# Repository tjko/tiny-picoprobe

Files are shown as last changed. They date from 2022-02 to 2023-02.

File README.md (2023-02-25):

# tiny-picoprobe

Tiny PicoProbe is a small PCB to mount Raspberry Pi Pico, when you want to use [PicoProbe](https://github.com/raspberrypi/picoprobe) to debug your [Raspberry Pi Pico](https://www.raspberrypi.com/products/raspberry-pi-pico/) projects without a breadboard...

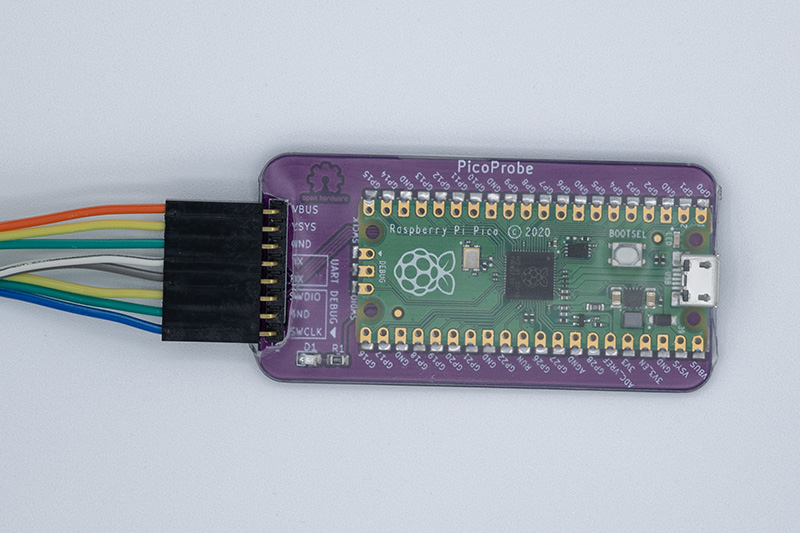
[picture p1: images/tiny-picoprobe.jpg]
Shrinkwrapped Tiny PicoProbe


This was created to make it "handsfree" to update firmware when developing [Fanpico (Smart PWM (PC) Fan Controller)](https://github.com/tjko/fanpico).

If you are not already familiar with PicoProbe see Appendix A in [Getting Started With Pico (PDF)](https://datasheets.raspberrypi.com/pico/getting-started-with-pico.pdf).

There is also tutorial here: [Raspberry Pi Pico and RP2040 - C/C++ Part 2: Debugging with VS Code](https://www.digikey.com/en/maker/projects/raspberry-pi-pico-and-rp2040-cc-part-2-debugging-with-vs-code/470abc7efb07432b82c95f6f67f184c0)

**Update (February 2023)**: There is finally official "picoprobe" available: [Raspberry Pi Debug Probe](https://www.raspberrypi.com/products/debug-probe/).  
which may be better choice if you're looking for ready-made solution. But if you prefer a DIY solution, continue reading...

New Debug Probe makes "tiny-picoprobe" look not so small anymore:

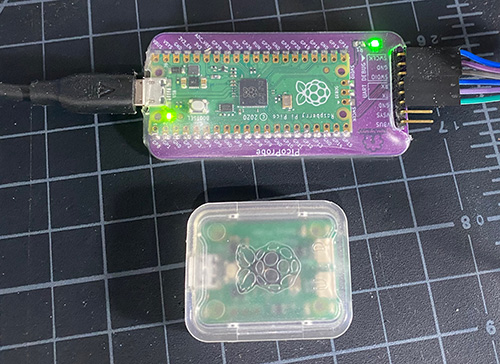
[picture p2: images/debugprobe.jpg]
size comparison


## PCB
PCB provides pinout to connect to Pico's SWD ("DEBUG") connector with flat (3-pin) ribbon cable, and it also has pinouts for UART and powering the Pico being programmed/debugged.

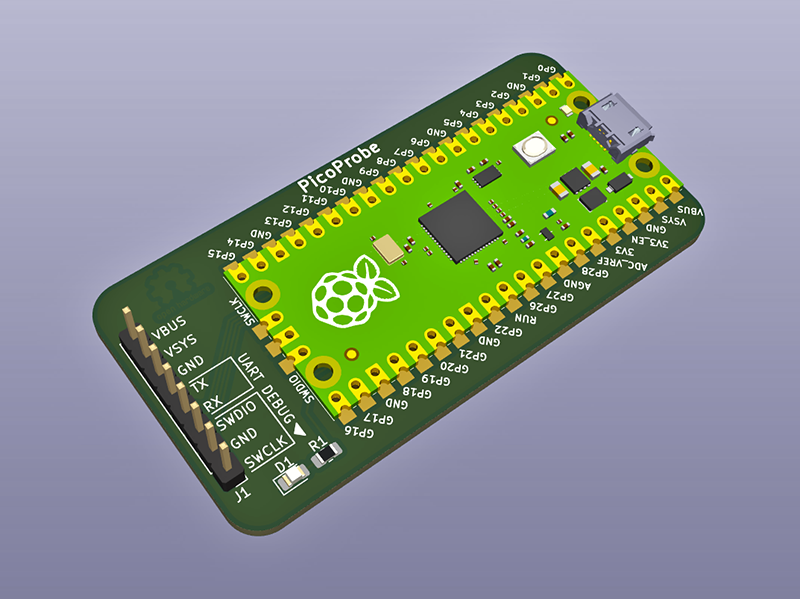
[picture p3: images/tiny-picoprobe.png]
Tiny PicoProbe PCB


Designed with [KiCad](https://www.kicad.org/) 6.0.  PCB allows mounting Pico directly or using headers:

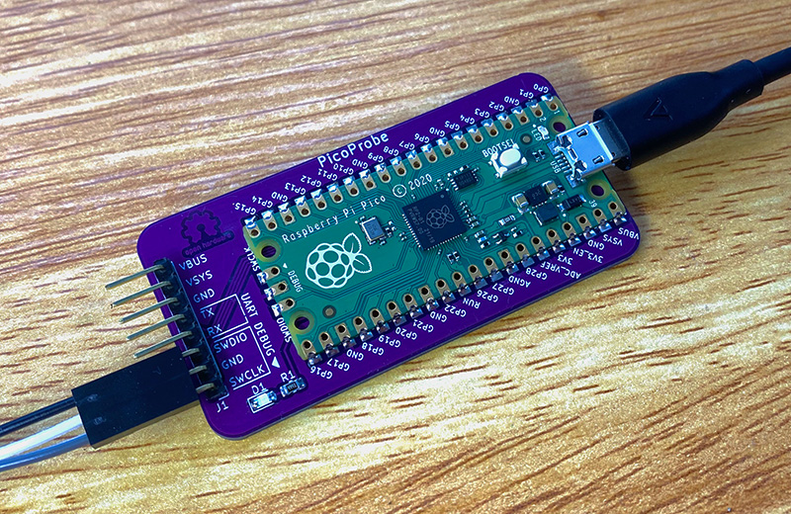
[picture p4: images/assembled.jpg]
Assembled Tiny PicoProbe

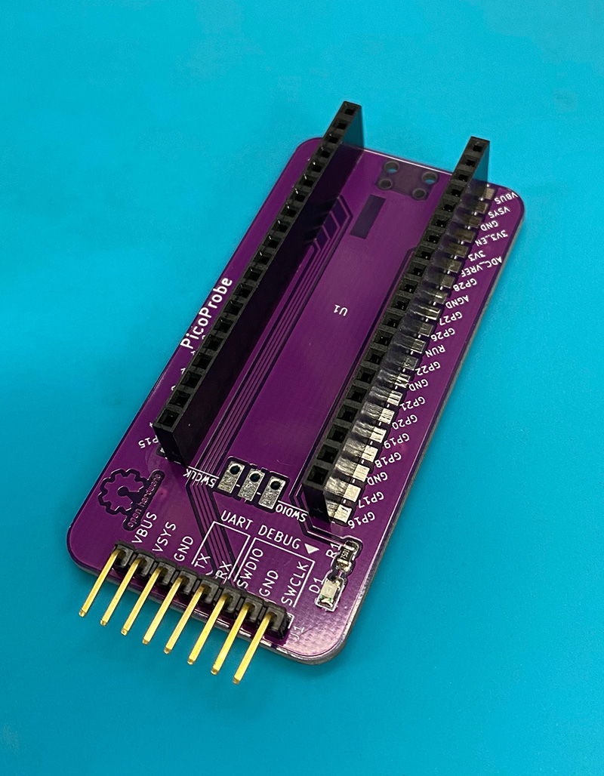
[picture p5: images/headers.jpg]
Tiny PicoProbe with headers


## Kerbers
Kerber files ready to be sent to a PCB maker (like JLCPCB, PCBWay, etc...):
* [PCB Version 1.0](kerbers/tiny-picoprobe-v1.zip)
* [PCB Version 1.1](kerbers/tiny-picoprobe-v1.1.zip)

You will only need the ZIP file (link above) to order PCBs. Simply upload the ZIP file to a PCB maker website. Then you typically only need to only select quantity and PCB color. If ordering from JLCPCB you can also choose to "Specify a location" in the Remove Order Number option (this will place order number on the PCB so that the Pico will cover it).

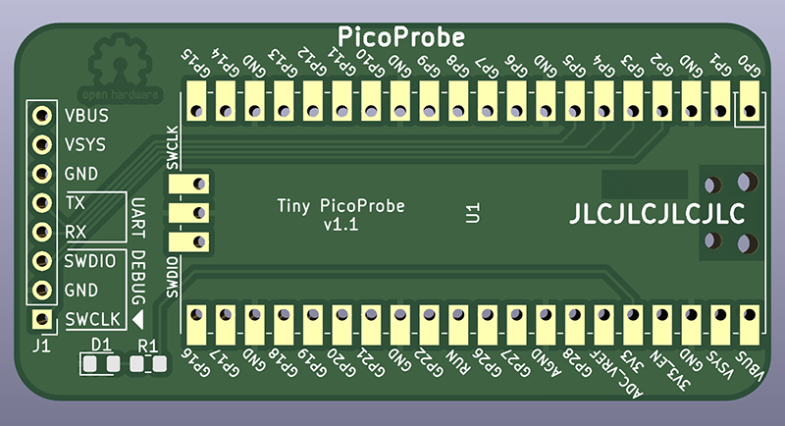
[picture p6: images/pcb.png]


## Assembly
PCB contains footprints for a 0805 size SMD LED and resistor to provide power indicator. Power indicator is optional.

ID|Type|Description|Mouser P/N|LCSC P/N
--|----|-----------|----------|---------
D1|LED (0805)|Pad is suitable for handsoldering 0805 size LEDs, 0603 should work as well...|710-150080GS75000 (?)|C434432
R1|7.5k (0805)|Depending on LED used choose appropriate resistor. Green high-intensity 0805 LEDs typically work nicely with resistor in 5k to 10k range|603-RC0805FR-077K5L|C229003

Note, if soldering Pico directly on the PCB, then 1" diameter shrink tubing can be used to wrap the pico and PCB in nice insulated package.

## DIY Kits

If you'd like to support Open Source Hardware development.  DIY Kits are made available in limited quantity.

Check availability here: [eBay](https://www.ebay.com/usr/oh6lxv)

## Credits
Idea for this PCB came from [Fabien-Chouteau/picoprobe-pcb](https://github.com/Fabien-Chouteau/picoprobe-pcb) (check his version as he sells it on Tindie).

KiCad Pico model/footprint that was used can be found here [ncarandini/KiCad-RP-Pico](https://github.com/ncarandini/KiCad-RP-Pico)

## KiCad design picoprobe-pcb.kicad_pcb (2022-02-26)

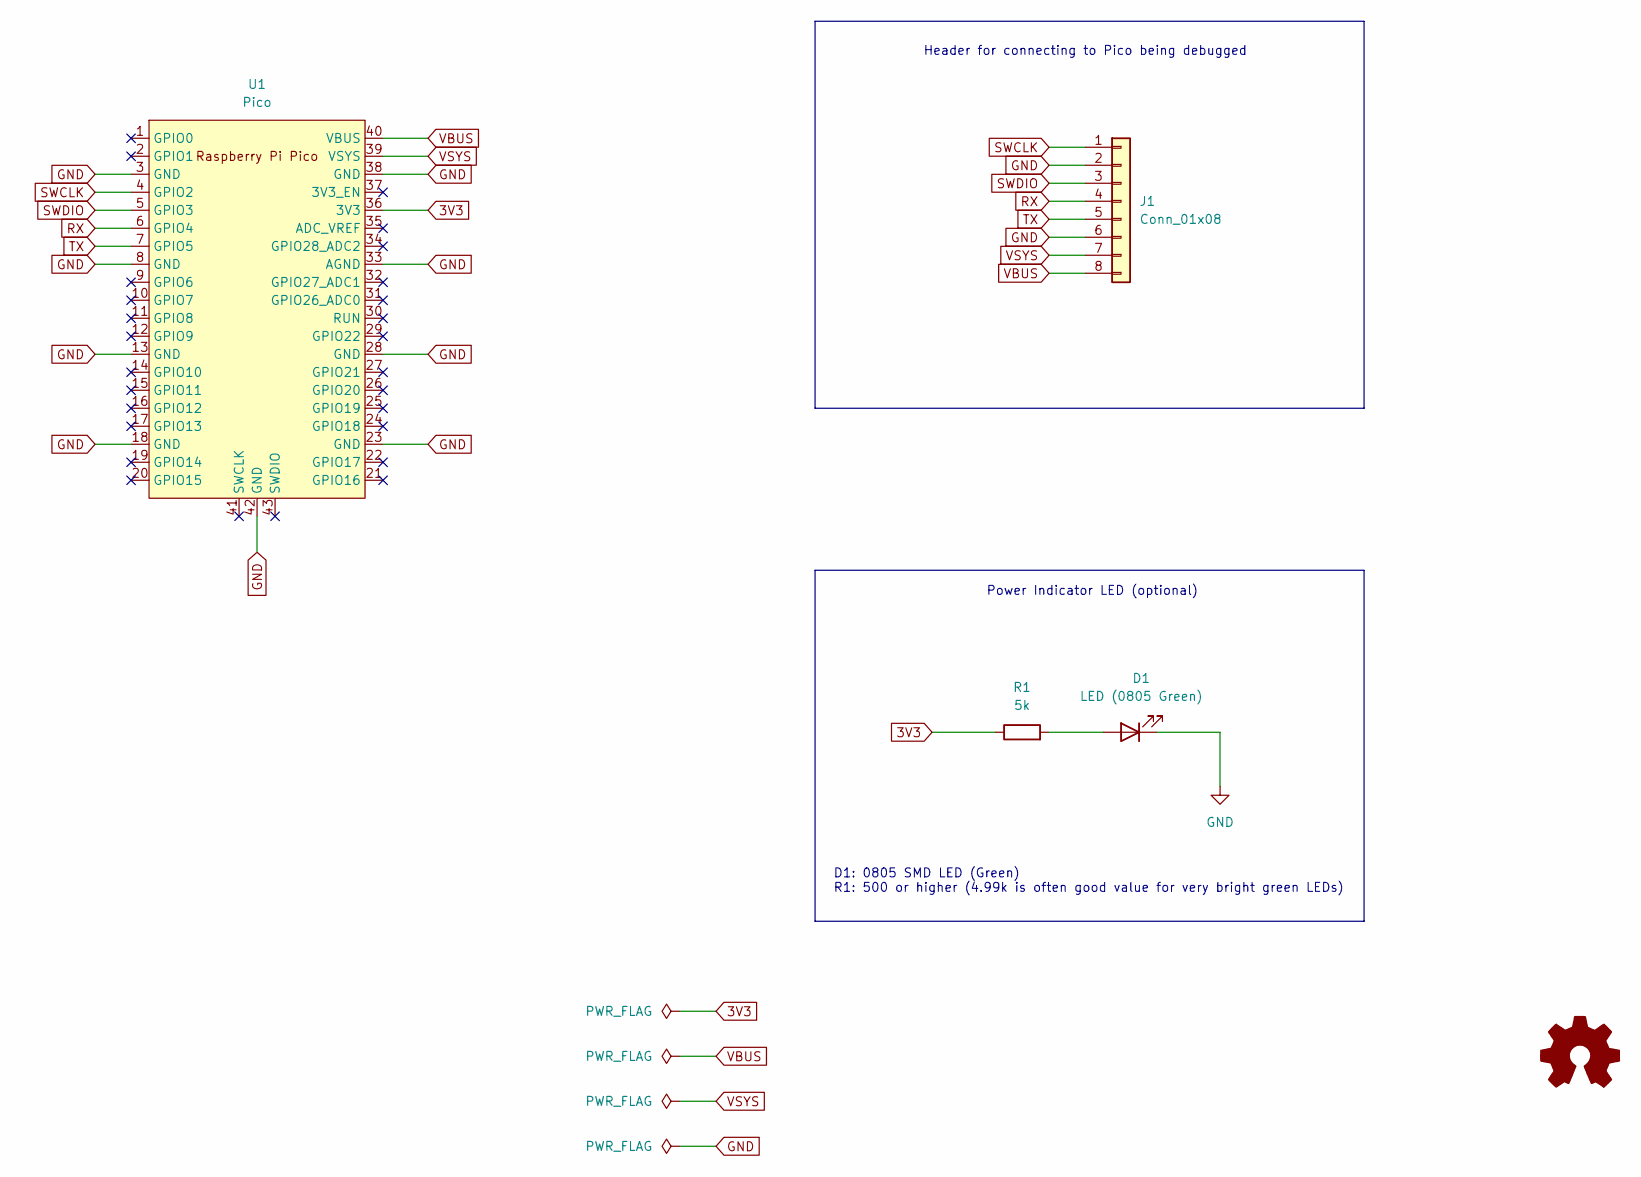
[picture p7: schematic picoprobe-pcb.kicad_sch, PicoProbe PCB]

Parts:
D1: LED (0805 Green); LED_0805_2012Metric_Pad1.15x1.40mm_HandSolder
J1: Conn_01x08; PinHeader_1x08_P2.54mm_Vertical
R1: 5k; R_0805_2012Metric_Pad1.20x1.40mm_HandSolder
U1: Pico; RPi_Pico_SMD_TH

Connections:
3V3: R1.1, U1.36 (3V3)
GND: D1.1 (K), J1.2, J1.6, U1.3 (GND), U1.8 (GND), U1.13 (GND), U1.18 (GND), U1.23 (GND), U1.28 (GND), U1.33 (AGND), U1.38 (GND), U1.42 (GND)
unnamed: D1.2 (A), R1.2
RX: J1.4, U1.6 (GPIO4)
SWCLK: J1.1, U1.4 (GPIO2)
SWDIO: J1.3, U1.5 (GPIO3)
TX: J1.5, U1.7 (GPIO5)
VBUS: J1.8, U1.40 (VBUS)
VSYS: J1.7, U1.39 (VSYS)

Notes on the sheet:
Header for connecting to Pico being debugged
D1: 0805 SMD LED (Green) R1: 500 or higher (4.99k is often good value for very bright green LEDs)
Power Indicator LED (optional)

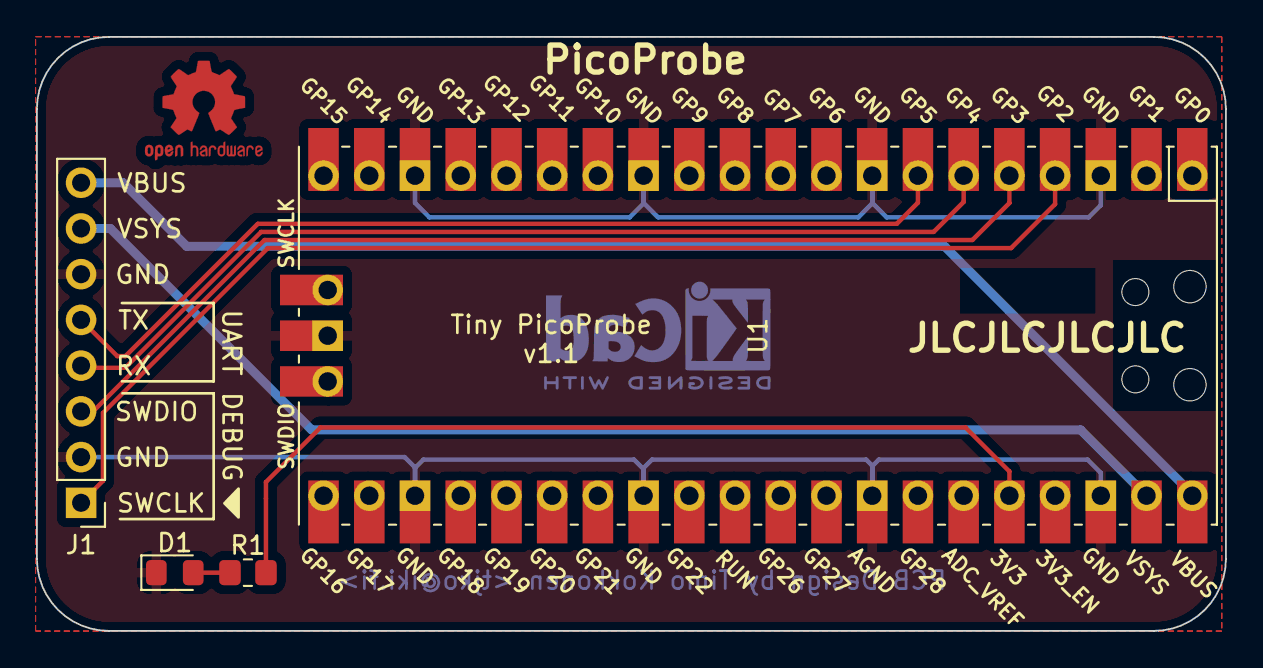
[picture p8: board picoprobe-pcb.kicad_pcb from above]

Board: 2 copper layers, 66.1 x 33.0 mm, 4 parts (0 on the bottom side), 9 nets.

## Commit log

2022-02-05 Add render of the pcb.
2022-02-05 Initial board version.
    [picoprobe-pcb.kicad_pcb, picoprobe-pcb.kicad_sch]
2022-02-26 Slightly improved PCB v1.1 and kerbers.
    [picoprobe-pcb.kicad_pcb]
2022-02-27 Added render of the PCB.
2022-10-14 Add photo of shrinkwrapped board.
